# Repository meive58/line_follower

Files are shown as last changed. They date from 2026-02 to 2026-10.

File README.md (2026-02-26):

# Seguidor de Linha com ESP32

Projeto de robô seguidor de linha utilizando ESP32, sensores QTR-8 Digital, giroscópio MPU-6050 e encoders para motores N20.

## Componentes Utilizados

| Componente | Descrição |
|---|---|
| ESP32 DevKit | Microcontrolador principal |
| QTR-8RC/QTR-8A | Array de 8 sensores infravermelhos para detecção de linha |
| MPU-6050 | Giroscópio e acelerômetro 6-DOF |
| Motor N20 com Encoder | Micro motor DC com encoder de quadratura |
| Ponte H (L298N/TB6612/DRV8833) | Driver para controle dos motores |

## Estrutura do Projeto

```
line_follower/
├── include/
│   └── pin_config.h        # Configuração de pinos (EDITE AQUI!)
├── lib/
│   ├── Encoder/
│   │   ├── encoder.h
│   │   └── encoder.cpp
│   ├── MotorDriver/
│   │   ├── motor_driver.h
│   │   └── motor_driver.cpp
│   ├── MPU6050/
│   │   ├── mpu6050.h
│   │   └── mpu6050.cpp
│   ├── PIDController/
│   │   ├── pid_controller.h
│   │   └── pid_controller.cpp
│   └── QTRSensor/
│       ├── qtr_sensor.h
│       └── qtr_sensor.cpp
├── src/
│   └── main.cpp            # Código principal
├── platformio.ini          # Configuração do PlatformIO
└── README.md               # Este arquivo
```

## Configuração dos Pinos

**IMPORTANTE**: Antes de compilar, edite o arquivo `include/pin_config.h` com os pinos que você escolher.

### Pinos Disponíveis no ESP32

| Pino | Recomendação |
|---|---|
| GPIO 0 | Evite (boot mode) |
| GPIO 1 | Evite (TX0 - debug serial) |
| GPIO 2 | LED onboard - pode usar |
| GPIO 3 | Evite (RX0 - debug serial) |
| GPIO 4 | Seguro |
| GPIO 5 | Seguro |
| **GPIO 6-11** | **NÃO USAR (flash interna)** |
| GPIO 12-33 | Seguros para uso geral |
| GPIO 34-39 | Apenas entrada (sem pull-up) |

### Exemplo de Configuração

```c
// Sensor QTR-8 (8 pinos GPIO)
#define QTR_SENSOR_0    32
#define QTR_SENSOR_1    33
#define QTR_SENSOR_2    25
#define QTR_SENSOR_3    26
#define QTR_SENSOR_4    27
#define QTR_SENSOR_5    14
#define QTR_SENSOR_6    12
#define QTR_SENSOR_7    13

// MPU-6050 (I2C)
#define MPU_SDA_PIN     21
#define MPU_SCL_PIN     22

// Encoders (4 pinos com suporte a interrupção)
#define ENCODER_LEFT_A  34
#define ENCODER_LEFT_B  35
#define ENCODER_RIGHT_A 36
#define ENCODER_RIGHT_B 39

// Motores (6 pinos)
#define MOTOR_LEFT_EN   4
#define MOTOR_LEFT_IN1  16
#define MOTOR_LEFT_IN2  17
#define MOTOR_RIGHT_EN  5
#define MOTOR_RIGHT_IN1 18
#define MOTOR_RIGHT_IN2 19

// Botões
#define BUTTON_START    23
#define BUTTON_CALIB    15
```

## Instalação

### Pré-requisitos

1. [Visual Studio Code](https://code.visualstudio.com/)
2. [Extensão PlatformIO](https://platformio.org/install/ide?install=vscode)

### Compilação e Upload

1. Abra a pasta `line_follower` no VS Code
2. Edite `include/pin_config.h` com seus pinos
3. Conecte o ESP32 via USB
4. Clique no botão "Upload" (→) na barra inferior do PlatformIO

## Uso

### Calibração

1. Ligue o robô e aguarde a inicialização
2. Pressione o botão **CALIB**
3. Mantenha o robô **imóvel** durante a calibração do giroscópio (~3s)
4. Mova o robô sobre a linha (preto e branco) por ~10 segundos
5. A calibração será salva automaticamente

### Execução

1. Posicione o robô sobre a linha
2. Pressione o botão **START**
3. Aguarde a contagem regressiva (3, 2, 1...)
4. O robô começará a seguir a linha

### LED de Status

| Estado | LED |
|---|-----|
| Aguardando | Pisca lento (1Hz) |
| Calibrando | Aceso fixo |
| Seguindo | Aceso fixo |
| Linha perdida | Pisca rápido (10Hz) |

## Ajuste do PID

Os ganhos do PID estão definidos no arquivo `src/main.cpp`:

```c
#define PID_KP  0.1f    // Proporcional
#define PID_KI  0.0001f // Integral
#define PID_KD  0.5f    // Derivativo
```

### Guia de Ajuste

1. **Comece com Ki = 0, Kd = 0**
2. **Aumente Kp** até o robô oscilar levemente
3. **Aumente Kd** para reduzir a oscilação
4. **Adicione Ki** (pequeno) se houver erro persistente

### Valores Sugeridos para Início

| Pista | Kp | Ki | Kd |
|---|----|----|----|
| Iniciante (curvas suaves) | 0.05 | 0.0001 | 0.3 |
| Intermediário | 0.1 | 0.0002 | 0.5 |
| Avançado (curvas fechadas) | 0.15 | 0.0005 | 0.8 |

## Diagrama de Conexões

```
                    ┌─────────────────┐
                    │     ESP32       │
                    └─────────────────┘
                            │
        ┌───────────────────┼───────────────────┐
        │                   │                   │
        ▼                   ▼                   ▼
┌───────────────┐   ┌───────────────┐   ┌───────────────┐
│   QTR-8       │   │   MPU-6050    │   │   Ponte H     │
│   (8 pinos)   │   │   (I2C)       │   │   (6 pinos)   │
└───────────────┘   └───────────────┘   └───────────────┘
                                                │
                                        ┌───────┴───────┐
                                        │               │
                                        ▼               ▼
                                ┌───────────┐   ┌───────────┐
                                │ Motor E   │   │ Motor D   │
                                │ + Encoder │   │ + Encoder │
                                └───────────┘   └───────────┘
```

## API dos Módulos

### QTRSensorArray

```cpp
void calibrate();                    // Calibra os sensores
uint16_t readLinePosition();         // Retorna posição (0-7000)
int16_t getError();                  // Retorna erro (-3500 a +3500)
bool isLineLost();                   // Verifica se perdeu a linha
bool detectCrossing();               // Detecta cruzamento
```

### MPU6050Sensor

```cpp
void calibrateGyro(uint16_t samples); // Calibra o giroscópio
void update();                        // Atualiza ângulos (chamar no loop)
float getYaw();                       // Retorna ângulo yaw em graus
void resetYaw();                      // Reseta yaw para zero
```

### Encoder

```cpp
long getCount();                     // Retorna contagem de pulsos
float getRPM();                      // Retorna velocidade em RPM
float getDistance(float diameter);   // Retorna distância percorrida
void resetCount();                   // Reseta contador
```

### MotorDriver

```cpp
void setSpeeds(int16_t left, int16_t right);  // Define velocidades
void forward(uint8_t speed);                   // Move para frente
void brake();                                  // Freia os motores
```

## Solução de Problemas

| Problema | Solução |
|---|---|
| ESP32 não conecta | Verifique o driver USB (CP210x ou CH340) |
| Sensores não calibram | Verifique as conexões e alimentação |
| Robô não segue a linha | Recalibre em ambiente adequado (iluminação constante) |
| Robô oscila muito | Reduza Kp ou aumente Kd |
| Robô perde a linha nas curvas | Aumente a velocidade base ou ajuste Kp |
| Motores não funcionam | Verifique alimentação da ponte H |

## Licença

Este projeto é livre para uso educacional.

## Autor

Desenvolvido como projeto de TCC.

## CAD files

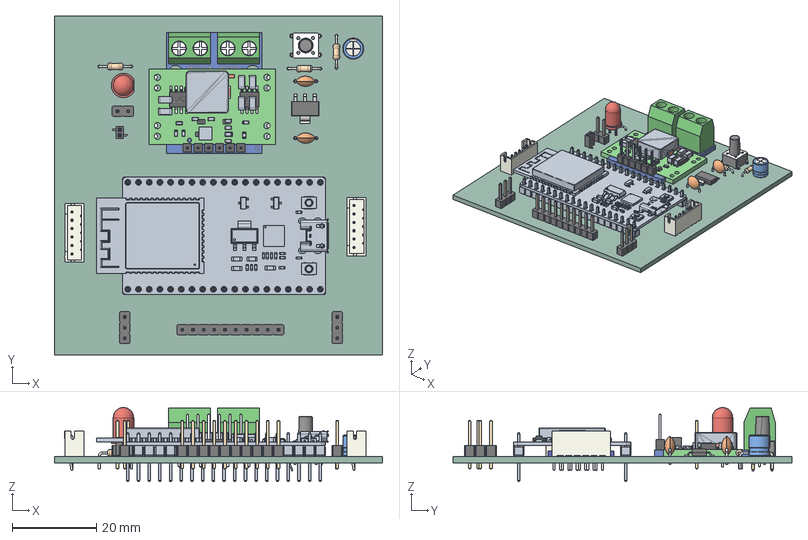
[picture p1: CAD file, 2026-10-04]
hardware/tcc.step
78.0 x 80.5 x 17.6 mm
SOT_223
CP_Radial_D50mm_P250mm
FSM8J
PinHeader_1x10_P254mm_Vertical
GY-521
PinHeader_1x03_P254mm_Vertical x 2
JST_B6B_PH_K x 2
PinHeader_1x02_P254mm_Vertical
LED_D5.0mm
C_Disc_D47mm_W25mm_P500mm x 2
R_Axial_DIN0204_L36mm_D16mm_P762mm_Horizontal x 3
L9110S (2 motor)
kicad_module_3D_MINI560 1
PinSocket_1x02_P1.27mm_Vertical_SMD_Pin1Left
ESP32-DEVKITC
tcc_PCB

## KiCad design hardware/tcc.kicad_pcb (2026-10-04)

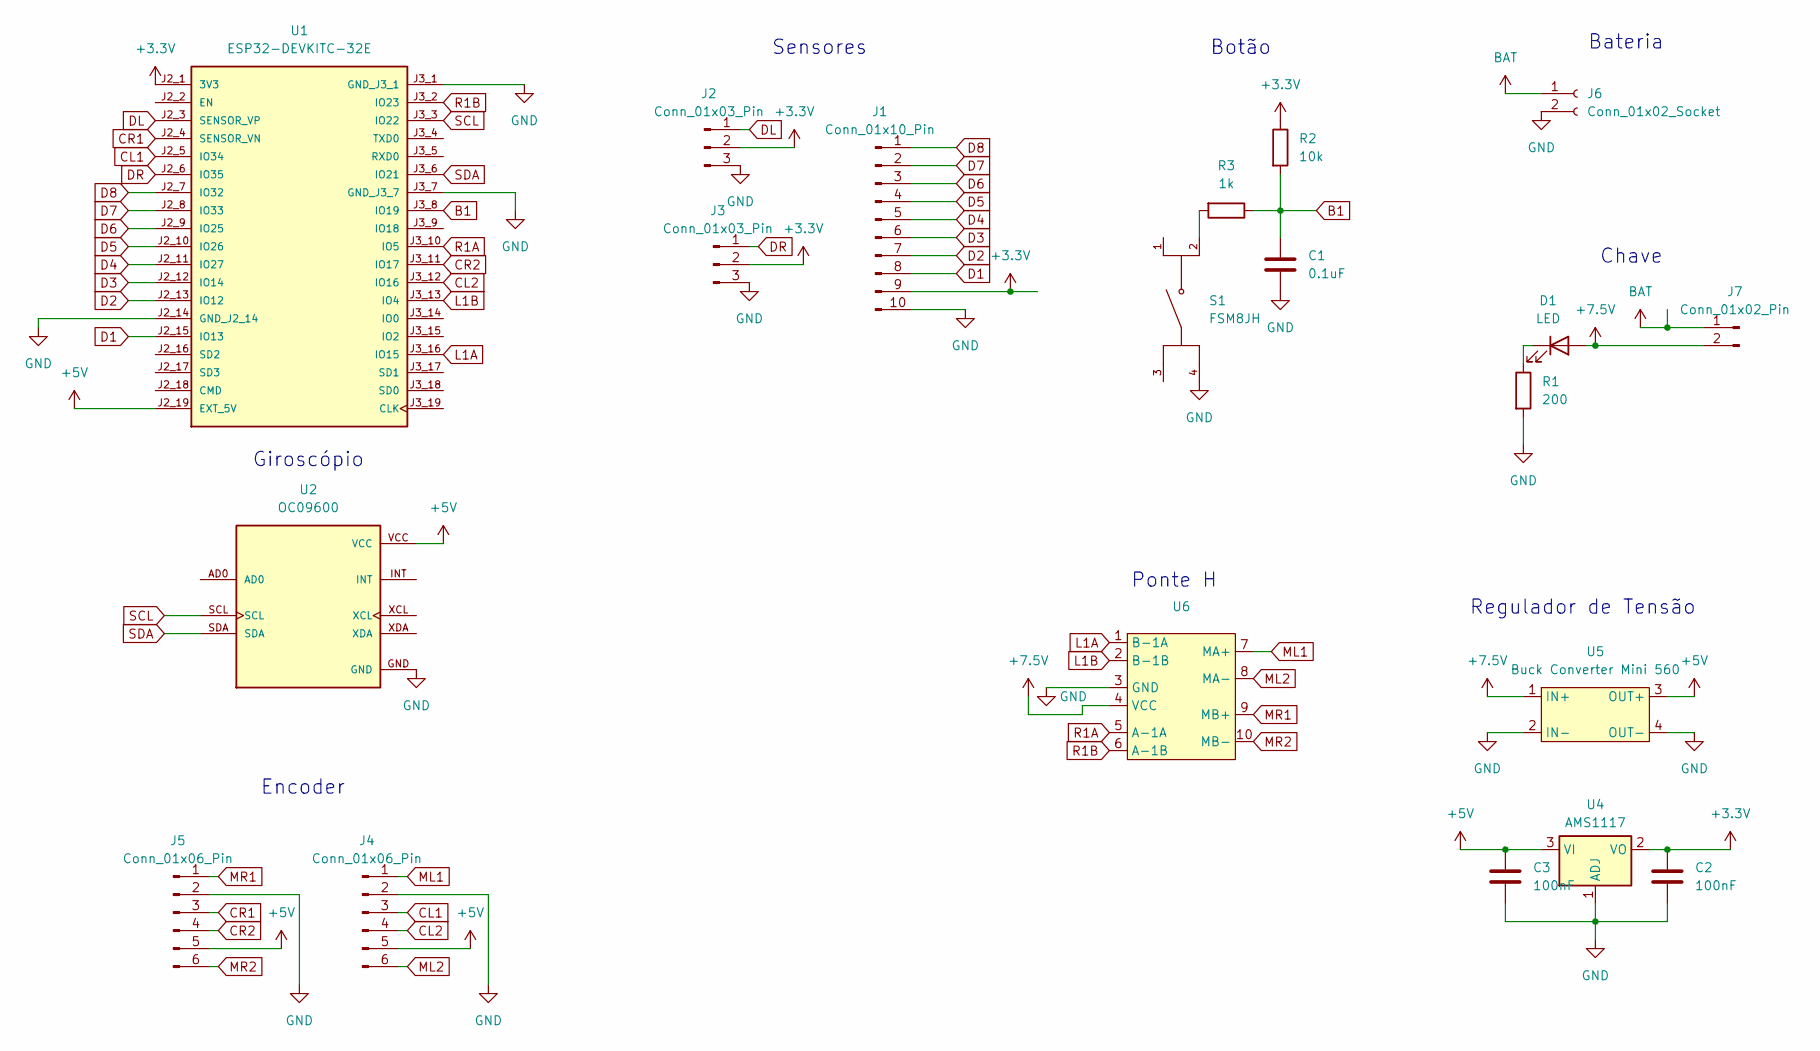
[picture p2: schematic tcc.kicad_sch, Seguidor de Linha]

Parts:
C1: 0.1uF; CP_Radial_D5.0mm_P2.50mm
C2, C3: 100nF; C_Disc_D4.7mm_W2.5mm_P5.00mm
D1: LED; LED_D5.0mm
J1: Conn_01x10_Pin; PinHeader_1x10_P2.54mm_Vertical
J2, J3: Conn_01x03_Pin; PinHeader_1x03_P2.54mm_Vertical
J4, J5: Conn_01x06_Pin; JST_PH_B6B-PH-K_1x06_P2.00mm_Vertical
J6: Conn_01x02_Socket; PinSocket_1x02_P1.27mm_Vertical_SMD_Pin1Left
J7: Conn_01x02_Pin; PinHeader_1x02_P2.54mm_Vertical
R1: 200; R_Axial_DIN0204_L3.6mm_D1.6mm_P7.62mm_Horizontal
R2: 10k; R_Axial_DIN0204_L3.6mm_D1.6mm_P7.62mm_Horizontal
R3: 1k; R_Axial_DIN0204_L3.6mm_D1.6mm_P7.62mm_Horizontal
S1: FSM8JH; SW_FSM8JH; PARTREV 8-1773450-9
U1: ESP32-DEVKITC-32E; MODULE_ESP32-DEVKITC-32E; PARTREV 1.4
U2: OC09600; MODULE_OC09600; PARTREV NA
U4: AMS1117; SOT-223-3_TabPin2
U5: Buck Converter Mini 560; Mini_560
U6: H_Bridge_L9110s_module

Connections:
+3.3V: C2.1, J1.9, J2.2, J3.2, R2.1, U1.J2_1 (3V3), U4.2 (VO)
+5V: C3.1, J4.5, J5.5, U1.J2_19 (EXT_5V), U2.VCC, U4.3 (VI), U5.3 (OUT+)
+7.5V: D1.2 (A), J7.2, U5.1 (IN+), U6.4 (VCC)
B1: C1.1, R2.2, R3.1, U1.J3_8 (IO19)
BAT: J6.1, J7.1
CL1: J4.3, U1.J2_5 (IO34)
CL2: J4.4, U1.J3_12 (IO16)
CR1: J5.3, U1.J2_4 (SENSOR_VN)
CR2: J5.4, U1.J3_11 (IO17)
D1: J1.8, U1.J2_15 (IO13)
D2: J1.7, U1.J2_13 (IO12)
D3: J1.6, U1.J2_12 (IO14)
D4: J1.5, U1.J2_11 (IO27)
D5: J1.4, U1.J2_10 (IO26)
D6: J1.3, U1.J2_9 (IO25)
D7: J1.2, U1.J2_8 (IO33)
D8: J1.1, U1.J2_7 (IO32)
DL: J2.1, U1.J2_3 (SENSOR_VP)
DR: J3.1, U1.J2_6 (IO35)
GND: C1.2, C2.2, C3.2, J1.10, J2.3, J3.3, J4.2, J5.2, J6.2, R1.2, S1.4, U1.J2_14 (GND_J2_14), U1.J3_1 (GND_J3_1), U1.J3_7 (GND_J3_7), U2.GND, U4.1 (ADJ), U5.2 (IN-), U5.4 (OUT-), U6.3 (GND)
L1A: U1.J3_16 (IO15), U6.1 (B-1A)
L1B: U1.J3_13 (IO4), U6.2 (B-1B)
ML1: J4.1, U6.7 (MA+)
ML2: J4.6, U6.8 (MA-)
MR1: J5.1, U6.9 (MB+)
MR2: J5.6, U6.10 (MB-)
unnamed: D1.1 (K), R1.1
unnamed: R3.2, S1.2
R1A: U1.J3_10 (IO5), U6.5 (A-1A)
R1B: U1.J3_2 (IO23), U6.6 (A-1B)
SCL: U1.J3_3 (IO22), U2.SCL
SDA: U1.J3_6 (IO21), U2.SDA

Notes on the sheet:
Botão
Encoder
Regulador de Tensão
Sensores
Chave
Giroscópio
Bateria
Ponte H

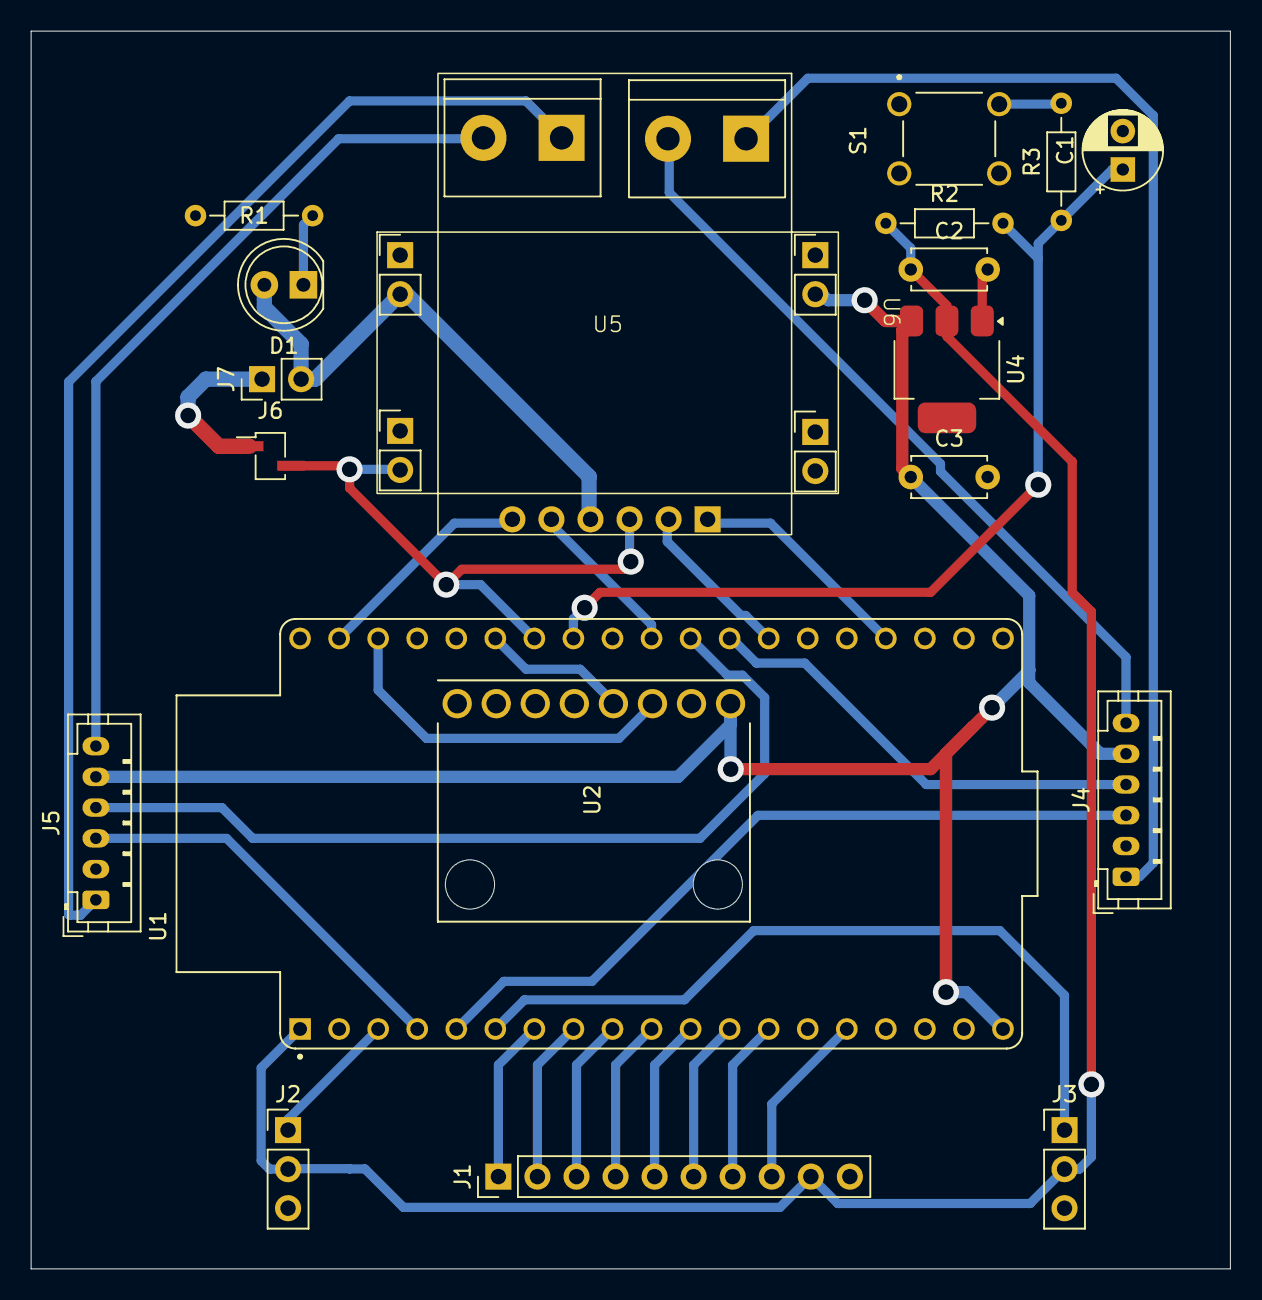
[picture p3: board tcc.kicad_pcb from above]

Board: 2 copper layers, 78.0 x 80.5 mm, 20 parts (0 on the bottom side), 32 nets.

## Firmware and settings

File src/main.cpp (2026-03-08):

/**
 * @file main.cpp
 * @brief Código principal do Seguidor de Linha com ESP32
 * 
 * Componentes:
 * - Array de sensores QTR-8 Digital
 * - Giroscópio/Acelerômetro MPU-6050
 * - Encoders de quadratura para motores N20
 * - Motores DC N20 com ponte H
 * 
 * @author Meive
 * @date 2026
 */

#include <Arduino.h>
#include "pin_config.h"
#include "qtr_sensor.h"
#include "mpu6050.h"
//#include "encoder.h"
#include "motor_driver.h"
#include "pid_controller.h"

// ============================================================================
// CONSTANTES E CONFIGURAÇÕES
// ============================================================================

// Velocidade base do robô (0-255)
#define BASE_SPEED          150

// Ganhos do PID para seguir linha (AJUSTE CONFORME NECESSÁRIO)
#define PID_KP              0.1f
#define PID_KI              0.0001f
#define PID_KD              0.5f

// Intervalo de atualização em ms
#define UPDATE_INTERVAL_MS  5

// Estados do robô
enum RobotState {
    STATE_IDLE,         // Parado, aguardando comando
    STATE_CALIBRATING,  // Calibrando sensores
    STATE_RUNNING,      // Seguindo linha
    STATE_LOST,         // Linha perdida
    STATE_FINISHED      // Fim do percurso
};

// ============================================================================
// OBJETOS GLOBAIS
// ============================================================================

QTRSensorArray qtrSensors;
MPU6050Sensor mpu;
//Encoder encoderLeft;
//Encoder encoderRight;
MotorDriver motors;
PIDController linePID;

// Estado atual do robô
RobotState currentState = STATE_IDLE;

// Variáveis de controle
unsigned long lastUpdateTime = 0;

// ============================================================================
// PROTÓTIPOS DE FUNÇÕES
// ============================================================================

void initializeSensors();
void calibrateSensors();
void updateSensors();
void followLine();
void handleLineLost();
void printDebugInfo();

// ============================================================================
// SETUP
// ============================================================================

void setup() {
    Serial.begin(115200);
    delay(1000);
    
    Serial.println("=====================================");
    Serial.println("   SEGUIDOR DE LINHA - ESP32");
    Serial.println("=====================================");
    Serial.println();
    
    // Configura LED de status
    pinMode(LED_STATUS, OUTPUT);
    digitalWrite(LED_STATUS, LOW);
    
    // Configura botões
    pinMode(BUTTON_START, INPUT_PULLUP);
    pinMode(BUTTON_CALIB, INPUT_PULLUP);
    
    // Inicializa todos os sensores e atuadores
    initializeSensors();
    
    Serial.println();
    Serial.println("[SISTEMA] Pronto!");
    Serial.println("[SISTEMA] Pressione CALIB para calibrar");
    Serial.println("[SISTEMA] Pressione START para iniciar");
    Serial.println();
    
    currentState = STATE_IDLE;
}

// ============================================================================
// LOOP PRINCIPAL
// ============================================================================

void loop() {
    // Verifica botão de calibração
    if (digitalRead(BUTTON_CALIB) == LOW && currentState == STATE_IDLE) {
        delay(50); // Debounce
        if (digitalRead(BUTTON_CALIB) == LOW) {
            calibrateSensors();
        }
        while (digitalRead(BUTTON_CALIB) == LOW); // Aguarda soltar
    }
    
    // Verifica botão de início
    if (digitalRead(BUTTON_START) == LOW && currentState == STATE_IDLE) {
        delay(50); // Debounce
        if (digitalRead(BUTTON_START) == LOW) {
            if (qtrSensors.isCalibrated()) {
                Serial.println("[SISTEMA] Iniciando em 3 segundos...");
                for (int i = 3; i > 0; i--) {
                    Serial.printf("[SISTEMA] %d...\n", i);
                    digitalWrite(LED_STATUS, HIGH);
                    delay(500);
                    digitalWrite(LED_STATUS, LOW);
                    delay(500);
                }
                Serial.println("[SISTEMA] GO!");
                currentState = STATE_RUNNING;
                linePID.reset();
            } else {
                Serial.println("[ERRO] Calibre os sensores primeiro!");
            }
        }
        while (digitalRead(BUTTON_START) == LOW); // Aguarda soltar
    }
    
    // Loop de controle com intervalo fixo
    unsigned long now = millis();
    if (now - lastUpdateTime >= UPDATE_INTERVAL_MS) {
        lastUpdateTime = now;
        
        // Atualiza leituras dos sensores
        updateSensors();
        
        // Máquina de estados
        switch (currentState) {
            case STATE_IDLE:
                // LED pisca lentamente
                digitalWrite(LED_STATUS, (millis() / 1000) % 2);
                break;
                
            case STATE_RUNNING:
                // LED aceso
                digitalWrite(LED_STATUS, HIGH);
                followLine();
                break;
                
            case STATE_LOST:
                // LED pisca rapidamente
                digitalWrite(LED_STATUS, (millis() / 100) % 2);
                handleLineLost();
                break;
                
            case STATE_FINISHED:
                motors.brake();
                digitalWrite(LED_STATUS, LOW);
                break;
                
            default:
                break;
        }
    }
}

// ============================================================================
// FUNÇÕES DE INICIALIZAÇÃO
// ============================================================================

void initializeSensors() {
    Serial.println("[INIT] Inicializando sensores...");
    
    // Array de pinos do QTR-8
    uint8_t qtrPins[QTR_SENSOR_COUNT] = {
        QTR_SENSOR_0, QTR_SENSOR_1, QTR_SENSOR_2, QTR_SENSOR_3,
        QTR_SENSOR_4, QTR_SENSOR_5, QTR_SENSOR_6, QTR_SENSOR_7
    };
    
    // Inicializa sensores QTR-8
    qtrSensors.init(qtrPins, QTR_EMITTER_PIN);
    
    // Inicializa MPU-6050
    if (!mpu.init(MPU_SDA_PIN, MPU_SCL_PIN, MPU_I2C_ADDRESS)) {
        Serial.println("[ERRO] Falha ao inicializar MPU-6050!");
    }
    
    // Inicializa encoders
    //encoderLeft.init(ENCODER_LEFT_A, ENCODER_LEFT_B, ENCODER_PPR, GEAR_RATIO, 0);
    //encoderRight.init(ENCODER_RIGHT_A, ENCODER_RIGHT_B, ENCODER_PPR, GEAR_RATIO, 1);
    
    // Inicializa motores
    /*motors.init(
        MOTOR_LEFT_EN, MOTOR_LEFT_IN1, MOTOR_LEFT_IN2,
        MOTOR_RIGHT_EN, MOTOR_RIGHT_IN1, MOTOR_RIGHT_IN2,
        PWM_FREQUENCY, PWM_RESOLUTION
    );*/
    
    // Inicializa controlador PID
    linePID.init(PID_KP, PID_KI, PID_KD);
    linePID.setOutputLimits(-255, 255);
    
    Serial.println("[INIT] Sensores inicializados!");
}

// ============================================================================
// FUNÇÕES DE CALIBRAÇÃO
// ============================================================================

void calibrateSensors() {
    currentState = STATE_CALIBRATING;
    
    Serial.println("\n========== CALIBRAÇÃO ==========");
    
    // Pisca LED durante calibração
    digitalWrite(LED_STATUS, HIGH);
    
    // Calibra giroscópio (manter parado)
    Serial.println("\n[CALIB] Mantenha o robô IMÓVEL...");
    delay(2000);
    mpu.calibrateGyro(500);
    
    // Calibra sensores de linha (mover sobre a linha)
    Serial.println("\n[CALIB] Mova o robô sobre a linha...");
    delay(1000);
    qtrSensors.calibrate();
    
    digitalWrite(LED_STATUS, LOW);
    
    Serial.println("\n[CALIB] Calibração concluída!");
    Serial.println("================================\n");
    
    currentState = STATE_IDLE;
}

// ============================================================================
// FUNÇÕES DE ATUALIZAÇÃO
// ============================================================================

void updateSensors() {
    // Atualiza MPU-6050 (filtro complementar)
    mpu.update();
    
    // Atualiza cálculo de velocidade dos encoders
    //encoderLeft.update();
    //encoderRight.update();
}

// ============================================================================
// FUNÇÕES DE CONTROLE
// ============================================================================

void followLine() {
    // Lê posição da linha
    uint16_t position = qtrSensors.readLinePositionWhite();
    
    // Verifica se perdeu a linha
    if (qtrSensors.isLineLost()) {
        currentState = STATE_LOST;
        return;
    }
    
    // Calcula erro (-3500 a +3500)
    int16_t error = qtrSensors.getError();
    
    // Calcula correção PID
    float correction = linePID.compute(error);
    /*
    // Aplica correção às velocidades dos motores
    int16_t leftSpeed = BASE_SPEED + correction;
    int16_t rightSpeed = BASE_SPEED - correction;
    
    // Garante que as velocidades estejam no range válido
    leftSpeed = constrain(leftSpeed, -255, 255);
    rightSpeed = constrain(rightSpeed, -255, 255);
    
    // Define velocidades dos motores
    motors.setSpeeds(leftSpeed, rightSpeed);
    */
    // Debug (descomente para ver valores)
    printDebugInfo();
}

void handleLineLost() {
    static unsigned long lostTime = 0;
    static int16_t lastKnownDirection = 0;
    
    // Primeira vez perdendo a linha
    if (lostTime == 0) {
        lostTime = millis();
        lastKnownDirection = qtrSensors.getError();
        Serial.println("[WARN] Linha perdida!");
    }
    /*
    // Tenta recuperar girando na última direção conhecida
    if (lastKnownDirection < 0) {
        motors.setSpeeds(-80, 80); // Gira para esquerda
    } else {
        motors.setSpeeds(80, -80); // Gira para direita
    }
    */
    // Verifica se encontrou a linha
    if (!qtrSensors.isLineLost()) {
        Serial.println("[INFO] Linha recuperada!");
        currentState = STATE_RUNNING;
        lostTime = 0;
        return;
    }
    
    // Timeout - desiste após 3 segundos
    if (millis() - lostTime > 3000) {
        Serial.println("[ERRO] Timeout - parando o robô");
        //motors.brake();
        currentState = STATE_IDLE;
        lostTime = 0;
    }
}

// ============================================================================
// FUNÇÕES DE DEBUG
// ============================================================================

void printDebugInfo() {
    static unsigned long lastPrint = 0;
    
    // Imprime a cada 200ms
    if (millis() - lastPrint < 200) return;
    lastPrint = millis();
    
    // Estado dos sensores QTR-8 (visual)
    uint16_t sensorValues[QTR_SENSOR_COUNT];
    qtrSensors.getSensorValues(sensorValues);
    
    Serial.print("QTR:[");
    for (uint8_t i = 0; i < QTR_SENSOR_COUNT; i++) {
        // Threshold de 500 para considerar "sobre a linha"
        if (sensorValues[i] > 500) {
            Serial.print("#");  // Sensor detectando linha (nível alto)
        } else {
            Serial.print("_");  // Sensor fora da linha (nível baixo)
        }
    }
    Serial.print("] | ");
    
    // Posição da linha
    Serial.printf("Pos:%4d | ", qtrSensors.getLastPosition());
    
    // Erro e PID
    Serial.printf("Err:%5d | P:%.1f I:%.1f D:%.1f | ", 
                  qtrSensors.getError(),
                  linePID.getP(), linePID.getI(), linePID.getD());
    
    // Encoders (RPM)
    //Serial.printf("L:%.1f R:%.1f RPM | ", 
    //              encoderLeft.getRPM(), encoderRight.getRPM());
    
    // Yaw do giroscópio
    Serial.printf("Yaw:%.1f", mpu.getYaw());
    
    Serial.println();
}

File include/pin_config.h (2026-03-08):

/**
 * @file pin_config.h
 * @brief Configuração de pinos do ESP32 para o seguidor de linha
 * 
 * INSTRUÇÕES: Modifique os valores abaixo conforme sua escolha de pinos.
 * Certifique-se de usar pinos válidos do ESP32 e evitar conflitos.
 * 
 * PINOS A EVITAR:
 * - GPIO 0: Boot mode (pode ser usado com cuidado)
 * - GPIO 1: TX0 (usado para debug serial)
 * - GPIO 3: RX0 (usado para debug serial)
 * - GPIO 6-11: Conectados à flash interna (NÃO USAR)
 * - GPIO 34-39: Apenas entrada (sem pull-up interno)
 */

#ifndef PIN_CONFIG_H
#define PIN_CONFIG_H

// ============================================================================
// SENSOR QTR-8 DIGITAL (8 sensores infravermelhos)
// ============================================================================
// Conecte os pinos de saída digital do QTR-8A aos pinos abaixo
// Ordem: Sensor mais à ESQUERDA até o mais à DIREITA do robô

#define QTR_SENSOR_0    13   // Sensor 1 (extrema esquerda) - ALTERE CONFORME NECESSÁRIO
#define QTR_SENSOR_1    12   // Sensor 2 - ALTERE CONFORME NECESSÁRIO
#define QTR_SENSOR_2    14   // Sensor 3 - ALTERE CONFORME NECESSÁRIO
#define QTR_SENSOR_3    27   // Sensor 4 - ALTERE CONFORME NECESSÁRIO
#define QTR_SENSOR_4    26   // Sensor 5 - ALTERE CONFORME NECESSÁRIO
#define QTR_SENSOR_5    25   // Sensor 6 - ALTERE CONFORME NECESSÁRIO
#define QTR_SENSOR_6    33   // Sensor 7 - ALTERE CONFORME NECESSÁRIO
#define QTR_SENSOR_7    32   // Sensor 8 (extrema direita) - ALTERE CONFORME NECESSÁRIO

#define QTR_EMITTER_PIN 0  // Pino de controle do LED IR (opcional, -1 se não usar)

// ============================================================================
// GIROSCÓPIO/ACELERÔMETRO MPU-6050
// ============================================================================
// Comunicação I2C - Use os pinos padrão ou configure customizados

#define MPU_SDA_PIN     21  // Pino SDA (padrão ESP32: GPIO 21) - ALTERE CONFORME NECESSÁRIO
#define MPU_SCL_PIN     22  // Pino SCL (padrão ESP32: GPIO 22) - ALTERE CONFORME NECESSÁRIO
#define MPU_INT_PIN     -1   // Pino de interrupção (opcional, -1 se não usar) - ALTERE CONFORME NECESSÁRIO

// Endereço I2C do MPU-6050 (0x68 se AD0=LOW, 0x69 se AD0=HIGH)
#define MPU_I2C_ADDRESS 0x68

// ============================================================================
// ENCODERS DOS MOTORES N20
// ============================================================================
// Use pinos com suporte a interrupção para melhor precisão

#define ENCODER_LEFT_A  0  // Canal A do encoder esquerdo - ALTERE CONFORME NECESSÁRIO
#define ENCODER_LEFT_B  5   // Canal B do encoder esquerdo - ALTERE CONFORME NECESSÁRIO

#define ENCODER_RIGHT_A 39   // Canal A do encoder direito - ALTERE CONFORME NECESSÁRIO
#define ENCODER_RIGHT_B 36  // Canal B do encoder direito - ALTERE CONFORME NECESSÁRIO

// Pulsos por revolução do encoder (ajuste conforme seu encoder)
#define ENCODER_PPR     7   // Pulsos por revolução (típico para N20: 7 ou 11)
#define GEAR_RATIO      100 // Relação de redução do motor N20 (ex: 100:1)

// ============================================================================
// CONTROLE DOS MOTORES (Driver Ponte H - L298N, TB6612, DRV8833, etc.)
// ============================================================================

// Motor Esquerdo
#define MOTOR_LEFT_EN   0   // PWM do motor esquerdo (Enable) - ALTERE CONFORME NECESSÁRIO
#define MOTOR_LEFT_IN1  3   // Direção 1 do motor esquerdo - ALTERE CONFORME NECESSÁRIO
#define MOTOR_LEFT_IN2  0  // Direção 2 do motor esquerdo - ALTERE CONFORME NECESSÁRIO

// Motor Direito
#define MOTOR_RIGHT_EN  0   // PWM do motor direito (Enable) - ALTERE CONFORME NECESSÁRIO
#define MOTOR_RIGHT_IN1 23   // Direção 1 do motor direito - ALTERE CONFORME NECESSÁRIO
#define MOTOR_RIGHT_IN2 1 // Direção 2 do motor direito - ALTERE CONFORME NECESSÁRIO

// Configurações PWM
#define PWM_FREQUENCY   20000   // Frequência PWM em Hz (20kHz - fora da faixa audível)
#define PWM_RESOLUTION  8       // Resolução PWM em bits (8 bits = 0-255)
#define PWM_CHANNEL_L   0       // Canal LEDC para motor esquerdo
#define PWM_CHANNEL_R   1       // Canal LEDC para motor direito

// ============================================================================
// BOTÕES E LEDs (Opcional)
// ============================================================================

#define BUTTON_START    19   // Botão de início - ALTERE CONFORME NECESSÁRIO
#define BUTTON_CALIB    18 // Botão de calibração - ALTERE CONFORME NECESSÁRIO
#define LED_STATUS      2 // LED de status (GPIO 2 = LED onboard) - ALTERE CONFORME NECESSÁRIO

// ============================================================================
// BUZZER (Opcional)
// ============================================================================

//#define BUZZER_PIN      0   // Pino do buzzer - ALTERE CONFORME NECESSÁRIO

#endif // PIN_CONFIG_H

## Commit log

2026-03-08 Update pin configuration and test qtr sensors and mpu
2026-10-04 adding kicad hardware files
    [tcc.kicad_pcb, tcc.kicad_sch, tcc.step]
2026-10-14 adicionando sensores laterais
2026-10-16 varredura i2c
2026-10-18 encoder and testing motors
2026-11-01 new pcb
2026-11-03 apoio motor tamanho certo
2026-11-03 correct pin config
2026-11-08 edited schematic
